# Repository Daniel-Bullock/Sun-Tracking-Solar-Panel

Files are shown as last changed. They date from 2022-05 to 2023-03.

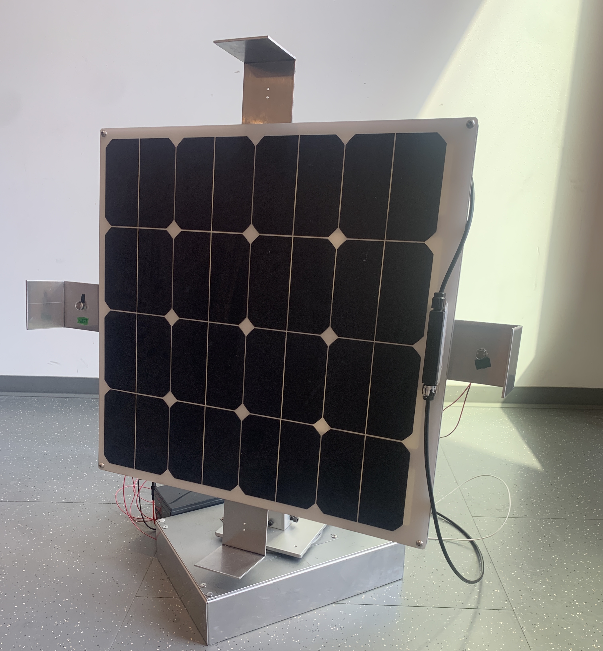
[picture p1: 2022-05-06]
models/Sun Tracking Solar Panel Image.jpeg

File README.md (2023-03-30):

# Sun Tracking Solar Panel



Sun Tracking Solar Panel Image

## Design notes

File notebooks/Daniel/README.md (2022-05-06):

# Lab Notebook

## 2/7/2022
Met to work on project proposal. Discusses planning for the project and put together a rough draft to show to and discuss with TA on 2/8.

## 2/10/2022
Met on discord to finish project proposal. Created 3D computer model of design rough draft. Made better block diagram. 

## 2/15/2022
Worked on PCB design

## 2/19/2022
Worked on PCB design

## 2/25/2022
Worked on PCB design

## 3/7/2022
Worked on PCB design, made sure it passed audit on PCBway, sent to Amr

## 3/12/2022
Researched web application

## 3/20/2022
Researched web application

## 3/23/2022
Talked with machine shop

## 3/25/2022
Researched web application, decided to switch to phone application

## 3/26/2022
Researched and tested wifi module

## 3/27/2022
Researched and tested wifi module

## 3/28/2022
Tested wifi module. Got it set up

## 3/30/2022
Finished individual progresss report

## 4/5/2022
Worked on phone application. Got Blynk figured out

## 4/7/2022
Worked on phone application. Got it working with blinking a light on a breadboard remotely

## 4/8/2022
Got phone application to display graphs. Got it working with reading voltage from power supply.

## 4/18/2022
Microcontroller arrived, began testing.

## 4/19/2022
Began testing programming the microcontroller. We plugged the programmer of the microcontroller and the power supply for the PCB in at the same time and ended up sending 10 Volts across the microcontroller. This ended up destroying the microcontroller. We decided to test the code for the wifi module instead and planned on desoldering another microcontroller off an arduino board we would acquire from the supply center.

## 4/20/2022
Voltage regulators broke. Bought new ones from supply center. PCB was busted from regulator burning out and we weren't sure if our circuit was right so we moved it to a breadboard. They didn't have a 3.3 volt regulator so we made a voltage divider. Got it working

## 4/21/2022
New power monitor chip arrived and programmer for microcontroller. We tried but couldn't figure out programming the microcontroller, so we decided to switch to an arduino redboard for our final design. 

## 4/22/2022
We recieved the solar panel from the machine shop today, it included a rotating base with the solar panel on an arm that allowed it to tilt as needed.  When testing the functionality of the motors with the solar panel the rotation motor was able to rotate the entire design but the tilt motor was not able to.  We tested the tilt motor at maximum rated power and it was still unable to move the panel.  We thought it was because the solar panel with the frame built by the machine shop was heavier than expected.

## 4/23/2022
Even though we decided to switch to using the RedBoard as our primary microcontroller, we still needed to use the PCB for our motor driver and our power monitor chip.  So we decided to desolder everything on the PCB and resolder the parts onto another copy of our PCB.  To get the signals from where the microcontroller would have been, Tyler soldered wires on the pads where the microcontroller would have been on the PCB.

## 4/24/2022
Now that we had everything soldered onto another PCB, we began testing the logic with the motor driver.  When we tried using the motor driver to turn the motors, the motors weren't moving.  When we connected the motors directly to power, they were turning.  We believed the issue was that the power supply wasn't producing the current required to turn the motors.

## 4/25/2022 - 4/26/2022 (all nighter)
We couldn't get the motor driver to work. We found out that one of the pins that we attacehd to ground on our PCB actually needed to be set to high, so we were always getting high signals on the positive and negative to the motor, causing them not to turn despite getting power, because they needed on high and one low to decide which direction to go. However when we tried desoldering it and fixing it with a wire manually setting it to high we ended up frying it. We decided that we would just have to use the redboard to program it. We were working on our project all night before the demo and manage to get it working on the horizontal mostly. The app worked as well.

## 5/1/2022
Worked on presentation.

## 5/2/2022
We recorded a video to demo our project for our presentation and worked on the presentation.

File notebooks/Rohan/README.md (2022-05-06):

# Sun Tracking Solar Panel

## 2/7/2022
 - Met with group over discord
 - Worked on project proposal to show TA 
    - Created first draft of block diagram
    - Discussed high-level requirements of project
    - Discussed requirements of subsystems

## 2/10/2022
 - Finished proposal with group

## 3/7/2022
 - Assisted with designing PCB and ensuring PCB passed audit

## 3/23/2022
 - Met with machine shop to discuss what they will be building for us
 - Got our PCB and our parts from the lab

## 3/24/2022
 - Tested parts and ensured our code Worked

## 3/30/2022
 - Completed and submitted individual progress report

## 4/18/2022
 - Microcontroller arrived today so we were able to begin testing

## 4/19/2022
 - We began testing programming the microcontroller.  We plugged the programmer of the microcontroller and the power supply for the PCB in at the same time and ended up sending 10 Volts across the microcontroller.  This ended up destroying the microcontroller.  We decided to test the code for the wifi module instead and planned on desoldering another microcontroller off an arduino board we would acquire from the supply center.

# 4/20/2022
 - One of our voltage regulators was not working so I went to the ECE supply center and purchased another voltage regulator.  I also purchased Arduino RedBoard.  This board had the same microcontroller on it so we desoldered the microcontroller off of it to use for our PCB.

# 4/21/2022
 - The programmer for our microcontroller arrived and a new power monitor.  We made sure that the settings in the IDE were correct and that each pad on the PCB was getting the proper voltage but we were still getting errors when trying to program the microcontroller.  Because of these issues programming the microcontroller with the programmer so we decided to use another Arduino RedBoard as our main microcontroller.  

# 4/22/2022
 - We recieved the solar panel from the machine shop today, it included a rotating base with the solar panel on an arm that allowed it to tilt as needed.  When testing the functionality of the motors with the solar panel the rotation motor was able to rotate the entire design but the tilt motor was not able to.  We tested the tilt motor at maximum rated power and it was still unable to move the panel.  We thought it was because the solar panel with the frame built by the machine shop was heavier than expected.

# 4/23/2022
 - Even though we decided to switch to using the RedBoard as our primary microcontroller, we still needed to use the PCB for our motor driver and our power monitor chip.  So we decided to desolder everything on the PCB and resolder the parts onto another copy of our PCB.  To get the signals from where the microcontroller would have been, Tyler soldered wires on the pads where the microcontroller would have been on the PCB.

## 4/24/2022
 - Now that we had everything soldered onto another PCB, we began testing the logic with the motor driver.  When we tried using the motor driver to turn the motors, the motors weren't moving.  When we connected the motors directly to power, they were turning.  We believed the issue was that the power supply wasn't producing the current required to turn the motors.

## 4/25/2022
 - While Tyler was working on the motor driver I realized that the reason the motor driver was working properly was because the power saving pin on the motor driver was shorted to ground.  This causes the motor driver to go into power saving mode, which effectively turns the motor driver off.  What we decided on doing was desoldering the motor driver and then resoldering it with electrical tape isolating the power saving pin from the PCB and then manually giving that pin 5 volts.  However, while we were desoldering the motor driver we damaged it and its functionality.  With limited time before our demo we decided to control only the rotation motor directly from the microcontroller as we had decided to scrap the tilt motor functionality.  We also connected the photoresistors to the flaps and were able to read data from the microcontroller.

## 4/26/2022
 - We finished integration of the sun tracking logic and the mobile app logic to run at the same time.  After finally putting each subsystem together, the solar panel could update its horizontal position and output statistics about the photoresistor values and the voltage and current values produced by the solar panel on a live graph.

## 5/2/2022
 - We recorded a video of our sun tracking solar panel working outside for the final presentation.  We also added the ability to manually move the panel using a button from the mobile app.

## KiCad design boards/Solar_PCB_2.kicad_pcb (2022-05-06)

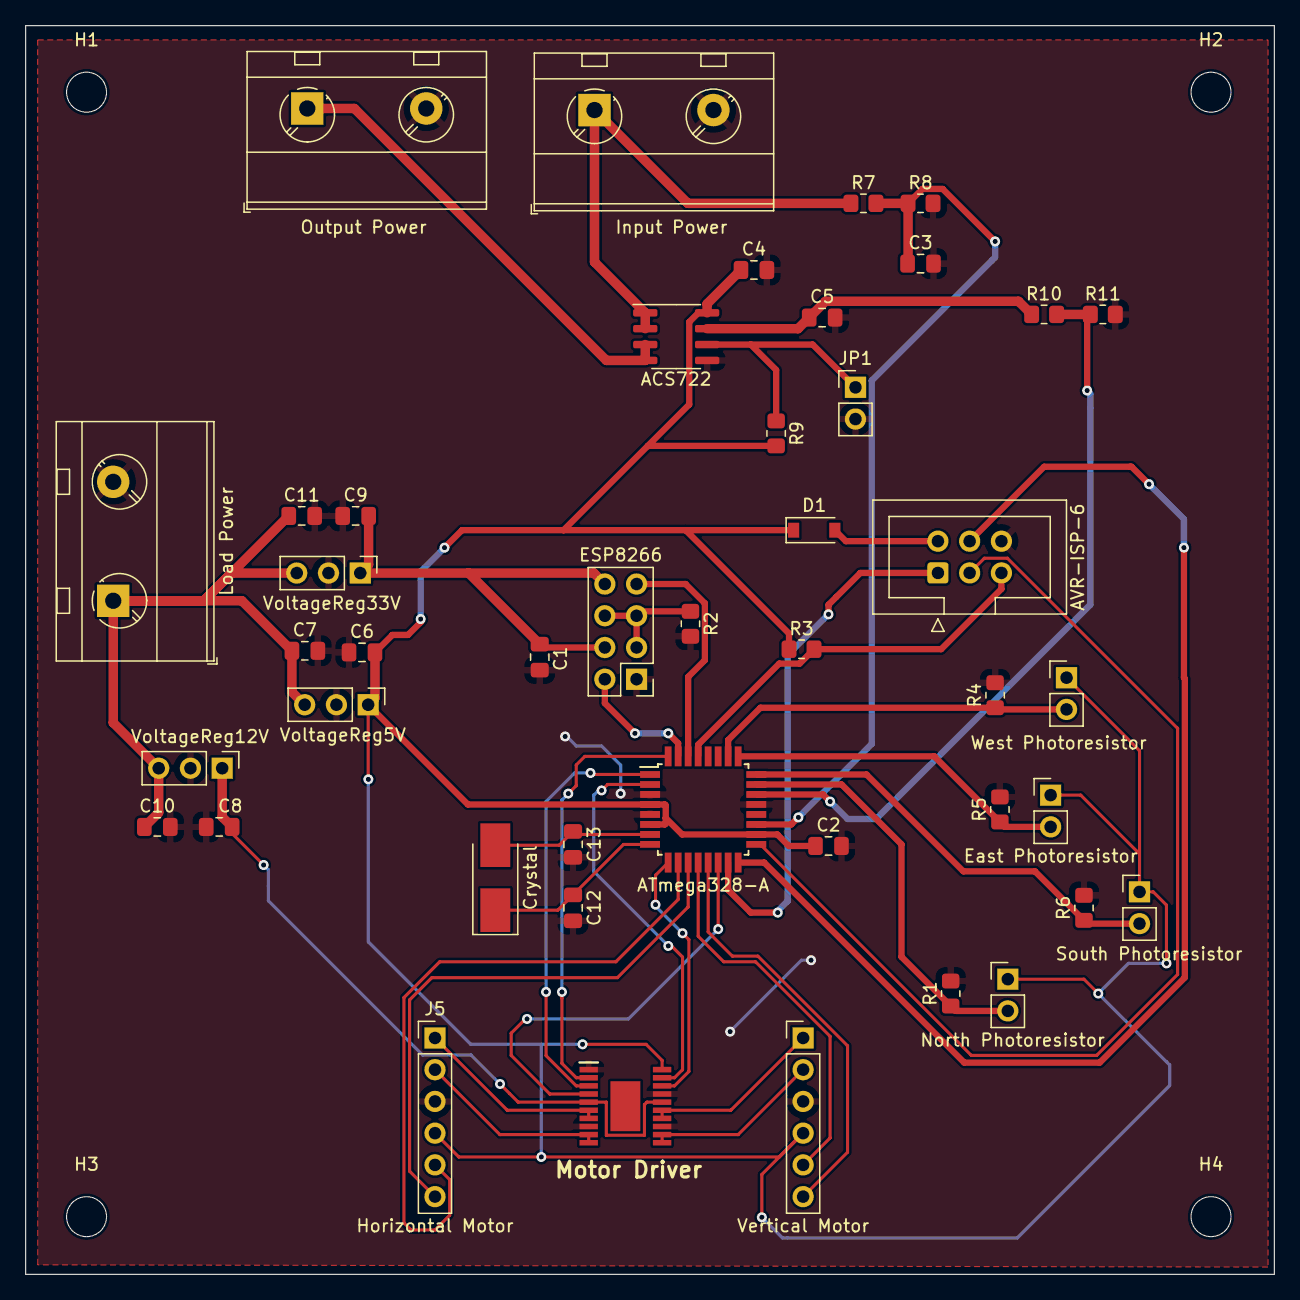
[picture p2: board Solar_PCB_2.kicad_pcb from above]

Board: 2 copper layers, 99.9 x 99.9 mm, 48 parts (0 on the bottom side), 38 nets.

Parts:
C1, C2, C6, C7, C8, C9, C10, C11: 1uF; C_0805_2012Metric_Pad1.18x1.45mm_HandSolder
C3, C4: .1uF; C_0805_2012Metric_Pad1.18x1.45mm_HandSolder
C5: 1nF; C_0805_2012Metric_Pad1.18x1.45mm_HandSolder
C12, C13: 22p; C_0805_2012Metric_Pad1.18x1.45mm_HandSolder
D1: MBR0520; D_SOD-123
H1, H2, H3, H4: MountingHole; MountingHole_3.2mm_M3
J1: Motor Driver; BD635
J1#2: ESP8266; PinHeader_2x04_P2.54mm_Vertical
J2: AVR-ISP-6; IDC-Header_2x03_P2.54mm_Vertical
J3: North Photoresistor; PinHeader_1x02_P2.54mm_Vertical
J4: West Photoresistor; PinHeader_1x02_P2.54mm_Vertical
J5: Horizontal Motor; PinHeader_1x06_P2.54mm_Vertical
J6: East Photoresistor; PinHeader_1x02_P2.54mm_Vertical
J7: South Photoresistor; PinHeader_1x02_P2.54mm_Vertical
J8: Vertical Motor; PinHeader_1x06_P2.54mm_Vertical
J9: Input Power; TerminalBlock_MetzConnect_Type703_RT10N02HGLU_1x02_P9.52mm_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
J10: Output Power; TerminalBlock_MetzConnect_Type703_RT10N02HGLU_1x02_P9.52mm_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
J11: VoltageReg5V; PinHeader_1x03_P2.54mm_Vertical
J12: Load Power; TerminalBlock_MetzConnect_Type703_RT10N02HGLU_1x02_P9.52mm_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
J13: VoltageReg12V; PinHeader_1x03_P2.54mm_Vertical
J14: VoltageReg33V; PinHeader_1x03_P2.54mm_Vertical
JP1: Jumper_2_Bridged; PinHeader_1x02_P2.54mm_Vertical
R1, R2, R3, R4, R5, R6, R7: 10k; R_0805_2012Metric_Pad1.20x1.40mm_HandSolder
R8: 3.8k; R_0805_2012Metric_Pad1.20x1.40mm_HandSolder
R9: 4.7k; R_0805_2012Metric_Pad1.20x1.40mm_HandSolder
R10: 1k; R_0805_2012Metric_Pad1.20x1.40mm_HandSolder
R11: 2k; R_0805_2012Metric_Pad1.20x1.40mm_HandSolder
U1: ACS722; SOIC-8_3.9x4.9mm_P1.27mm
U2: ATmega328-A; TQFP-32_7x7mm_P0.8mm
Y1: Crystal; Crystal_SMD_5032-2Pin_5.0x3.2mm_HandSoldering

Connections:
+3V3: C1.1, C9.2, J1#2.4, J1#2.8, J14.1
+5V: C2.1, C4.1, C6.2, D1.1 (K), J1.20 (VCC), J3.1, J4.1, J5.4, J6.1, J7.1, J8.4, J11.1, R3.1, R9.2, U1.8 (VCC), U2.4 (VCC), U2.6 (VCC), U2.18 (AVCC)
+12V: C8.2, J1.5 (VM_1), J1.16 (VM_2), J13.1
/B+: C7.1, C10.1, C11.1, J11.3, J12.1, J13.3, J14.3
/EAST: J6.2, R5.1, U2.25 (PC2)
/H_ENC_A: J5.5, U2.10 (PD6)
/H_ENC_B: J5.6, U2.11 (PD7)
/IN1A: J1.2 (IN1A), U2.32 (PD2)
/IN1B: J1.3 (IN1B), U2.1 (PD3)
/IN2A: J1.19 (IN2A), U2.2 (PD4)
/IN2B: J1.18 (IN2B), U2.9 (PD5)
/MISO: J2.1 (MISO), U2.15 (PB3)
/MOSI: J2.4 (MOSI), U2.16 (PB4)
/MP_H+: J1.6 (OUT1A_1), J1.7 (OUT1A_2), J5.1
/MP_H-: J1.9 (OUT1B_1), J1.10 (OUT1B_2), J5.2
/MP_V+: J1.14 (OUT2A_1), J1.15 (OUT2A_2), J8.1
/MP_V-: J1.11 (OUT2B_1), J1.12 (OUT2B_2), J8.2
/NORTH: J3.2, R1.1, U2.23 (PC0)
/PANEL_CURRENT: R10.2, R11.1, U2.22 (ADC7)
/PANEL_DIVIDER: J9.1, R7.1, U1.1 (IP+), U1.2 (IP+)
/PANEL_VOLTAGE: C3.1, R7.2, R8.1, U2.19 (ADC6)
/PWM: J1.4 (PWM), U2.14 (PB2)
/RESET: J2.5 (~RST), R3.2, U2.29 (~RESET/PC6)
/RXI: J1#2.7, U2.30 (PD0)
/SCK: J2.3 (SCK), U2.17 (PB5)
/SOUTH: J7.2, R6.1, U2.24 (PC1)
/TXO: J1#2.2, U2.31 (PD1)
/VIOUT: C5.1, R10.1, U1.7 (VIOUT)
/V_ENC_A: J8.5, U2.12 (PB0)
/V_ENC_B: J8.6, U2.13 (PB1)
/WEST: J4.2, R4.1, U2.26 (PC3)
GND: C1.2, C2.2, C3.2, C4.2, C5.2, C6.1, C7.2, C8.1, C9.1, C10.2, C11.2, C12.2, C13.2, J1.1 (GND), J1.8 (PGND_1), J1.13 (PGND_2), J1.17 (PS), J1#2.1, J2.6 (GND), J5.3, J8.3, J9.2, J10.2, J11.2, J12.2, J13.2, J14.2, JP1.2 (B), R1.2, R2.2, R4.2, R5.2, R6.2, R8.2, R11.2, U1.5 (GND), U2.3 (GND), U2.5 (GND), U2.21 (GND)
unnamed: C12.1, U2.8 (XTAL2/PB7), Y1.1
unnamed: C13.1, U2.7 (XTAL1/PB6), Y1.2
unnamed: D1.2 (A), J2.2 (VCC)
unnamed: J1#2.3, J1#2.5, J1#2.6, R2.1
unnamed: J10.1, U1.3 (IP-), U1.4 (IP-)
unnamed: JP1.1 (A), R9.1, U1.6 (BW_SEL)

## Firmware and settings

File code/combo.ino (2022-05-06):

// Template ID, Device Name and Auth Token are provided by the Blynk.Cloud
// See the Device Info tab, or Template settings
#define BLYNK_TEMPLATE_ID "TMPLw8mKIMCy"
#define BLYNK_DEVICE_NAME "Solar Panel Data"
#define BLYNK_AUTH_TOKEN "-_vlcjMXEiEdW8NrMt9-Wo-7zYum7s9l"
#define mV_per_amp 200

#define LED_pin 8  //not sure if this works as output pin
#define voltage_pin A2
#define current_pin A3
#define east_pin A0
#define west_pin A1
#define motor_red_pin 12   //wire with green tape
#define motor_black_pin 13\



#define BLYNK_PRINT Serial
#define ESP8266_BAUD 9600


#include <ESP8266_Lib.h>
#include <BlynkSimpleShieldEsp8266.h>

//Software Serial for Uno
#include <SoftwareSerial.h>
SoftwareSerial EspSerial(4, 5); // TX from chip goes in 6 (RX pin), Green wire(aka RX) goes in 7 (TX pin) TX(chip)->RX(mcu), RX(chip)->TX(mcu)


char auth[] = BLYNK_AUTH_TOKEN;

// Your WiFi credentials.
// Set password to "" for open networks.
char ssid[] = "Daniel's Laptop";
char pass[] = "solarpanel";
int pos=0;
int doTrack;
int manualControl;
int manualEast;
int manualWest;

ESP8266 wifi(&EspSerial);

//LED test to test if Blynk and wifi chip are working
// This function will be called every time Slider Widget
// in Blynk app writes values to the Virtual Pin V6
BLYNK_WRITE(V6)
{
  int pinValue = param.asInt(); // assigning incoming value from pin V5 to a variable

  // process received value
  digitalWrite(LED_pin,pinValue);
}

BLYNK_WRITE(V7)
{
  doTrack = param.asInt(); // assigning incoming value from pin V7 to a variable
  //Serial.print(doTrack);
}

BLYNK_WRITE(V8)
{
  manualControl = param.asInt(); // assigning incoming value from pin V7 to a variable
  //Serial.print(doTrack);
}
BLYNK_WRITE(V9)
{
  manualEast = param.asInt(); // assigning incoming value from pin V7 to a variable
  //Serial.print(doTrack);
}
BLYNK_WRITE(V10)
{
  manualWest = param.asInt(); // assigning incoming value from pin V7 to a variable
  //Serial.print(doTrack);
}



BlynkTimer power_data_timer;
void voltage_event()
{
  double temp_voltage = 0;
  double temp_current = 0;

  double volttest = analogRead(voltage_pin);
  Serial.println(volttest);
  for (int i = 0; i < 100; i++)
  {
    temp_voltage = temp_voltage + analogRead(voltage_pin);
    temp_current = temp_current + analogRead(current_pin);
  }
  //Serial.print(temp_voltage);
  double volt_configured = temp_voltage/100;
  double volt_configured2 = volt_configured*5/1024;
  //Serial.println(volt_configured);
  double panel_voltage = volt_configured2 * ((10+2)/2);

  //Serial.print("Voltage:    ");
  //Serial.println(panel_voltage);  //voltage divider
  Blynk.virtualWrite(V0, panel_voltage);  //write voltage

  int current_offset = 500 ; // .1 * vcc (mV) (ideally, we should measure to see)

  double panel_current_voltage = (temp_current/100) * (5000/1024);
  double current_scale = (1+2)/2;
  double panel_current = (panel_current_voltage*current_scale - current_offset)/mV_per_amp;
  //Serial.print("Current:    ");
  //Serial.println(panel_current);  //voltage divider
  Blynk.virtualWrite(V1, panel_current);  //write current to Blynk

  double panel_power = panel_voltage * panel_current / 1000;
  Blynk.virtualWrite(V2, panel_power);  //write power to Blynk
  
  double EAST, WEST;
  double diffh, temph;
  EAST = analogRead(east_pin);
  WEST = analogRead(west_pin);
  //Serial.println(west_pin);

  diffh = abs(EAST-WEST);
  temph = (EAST+WEST)/2;
  diffh = 100*(diffh/temph);

  String str1 = "";
  String str2 = "";
  String str3 = "";

  power_data_timer.setTimeout(3000L, ActionOFF);  // Run ActionOFF function in 3 seconds
  //Serial.print(pos);
  if (diffh >= .00001){
      if(EAST<WEST && (pos<30)){ //if east voltage is lower(aka resistance is higher), move clockwise
        str3 = "Move east.";
        Serial.print("East: ");
        Serial.print(String(EAST));
        Serial.print(" West: ");
        Serial.print(String(WEST));
        if(doTrack == 1){
          setMotor(-1);
          pos+=1;
          delay(1000);
        } 
      }
      else if(pos>-30){         //else the west resistance is higher, move west 1 degree to balance
        str3 = "Move west.";
        Serial.print("East: ");
        Serial.print(String(EAST));
        Serial.print(" West: ");
        Serial.print(String(WEST));
        if(doTrack == 1){
          setMotor(1);
          pos-=1;
          delay(1000);
        }
      }
      setMotor(0);
      //delay(500);
  }
  if(manualControl == 1 && doTrack == 0){
          if (manualEast == 1){
            setMotor(-1);
            //delay(1000);
          }
          if (manualWest == 1){
            setMotor(1);
            //delay(1000);
          }
  }
  double east_voltage = EAST*5/1024;
  double west_voltage = WEST*5/1024;
  str1 = "East: " + String(east_voltage, 2);
  str2 = "West: " + String(west_voltage, 2);
  // Send it to the server
  Blynk.virtualWrite(V3, str1);
  Blynk.virtualWrite(V4, str2);
  Blynk.virtualWrite(V5, str3);

} 

//null function just to have timing
void ActionOFF(){

}


void setMotor(int dir) {

  if (dir == 1) { //clockwise
    digitalWrite(12, HIGH);
    digitalWrite(13, LOW);
  }
  else if (dir == -1) {
    digitalWrite(12, LOW);
    digitalWrite(13, HIGH);
  }
  else {
    digitalWrite(12, LOW);
    digitalWrite(13, LOW);
  }
}




void setup()
{
  // Debug console
  pinMode(LED_pin,OUTPUT);
  pinMode(east_pin, INPUT);  //east
  pinMode(west_pin, INPUT);   //west
  pinMode(voltage_pin, INPUT);
  pinMode(current_pin, INPUT);
  pinMode(motor_red_pin, OUTPUT);  //motor
  pinMode(motor_black_pin, OUTPUT);  //motor
  Serial.begin(115200);

  // Set ESP8266 baud rate
  EspSerial.begin(ESP8266_BAUD);
  delay(10);

  Blynk.begin(auth, wifi, ssid, pass);

  power_data_timer.setInterval(1000L, voltage_event);
}

void loop()
{
  Blynk.run();
  power_data_timer.run();
}
